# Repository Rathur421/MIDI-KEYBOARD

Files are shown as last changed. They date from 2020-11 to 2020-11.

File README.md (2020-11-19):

# 🎹 ARDUINO UNO BASED MIDI KEYBOARD WITH VELOCITY V0.1


The documentation of the code is currently being made as well as the code improved.

This project use the [Arduino MIDI Library](https://github.com/FortySevenEffects/arduino_midi_library)

:warning: the easiest way will always be to buy a midi-keyboard

Up to 88 Key(and more if needed) currently tested for 61 key without major issues.

This github repo is made to propose some (I hope) helpfull ressources to make a MIDI Keyboard wich take in charge the velocity using an arduino-uno and some multiplexer(74HC4051). This my first:

- ARDUINO based project.
- [ARDUINO library](https://github.com/Rathur421/MIDI-KEYBOARD/tree/Master/PCB/circuit) (and first C++ program).
- [PCB conception](https://github.com/Rathur421/MIDI-KEYBOARD/tree/Master/Arduino_Code/lib).

so please try to not be too rude.

The file for the arduino shield conception are [here](https://github.com/Rathur421/MIDI-KEYBOARD/tree/Master/PCB/circuit). The file were created using [Kicad](https://kicad.org/).

## How the shield works


The number of pin on an arduino is clearly not sufficient to plug directly a keyboard matrice of a large keyboard so the idea is to use some multiplexer/demultiplexer to help us.

The biggest problem of this basic idea is that the more key you had the longueur will be the execution of the loop and the less precise will be the velocity.

we use only 1 demultiplexer `READMUX` and up to 3 multiplexer `WRITE_MUX`.
They are globally define in the code ([here](https://github.com/Rathur421/MIDI-KEYBOARD/blob/Master/Arduino_Code/lib/VeloceKey/src/VeloceKey.cpp) line 4 and 6) as they are dependent of the architecture of the project.

The switch between the different multiplexer is made by activating the pin to which each of the multiplexer is link in the PCB(from pin 11 to 13 of the arduino uno board) in the [main] program (from line 23 to 30).

## How the code works

You need to initialise all the key of your actual keyboard and put it in an array as in [main][main] from line 60 and 130.

Then you update all the key and check if the state changed based on the method `YOUR_VELOCEKEY.getKeyChanged()`.
If the state changed you can do the following:

- If it is in state 2 you can send a `MIDI.sendNoteOn(YOUR_VELOCEKEY.getNote(), YOUR_VELOCEKEY.getVelocity(), 1);`.
- If it is in state 3 you can send a `MIDI.sendNoteOff(YOUR_VELOCEKEY.getNote(), YOUR_VELOCEKEY.getVelocity(), 1);`.

That is made in the function update in [main][main] from line 20 to 58.

The code use principally the library [VeloceKey](###well-how-does-the-veloceKey-library-works)

### Well how does the VeloceKey library works?

This library is made to be intuitive for the user as each physical key of the keyboard correspond to a VeloceKey object in the program.

The VeloceKey object is built around a state byte to take the less place possible of the 2kB of RAM available on the Arduino Uno.

| bit position | 7 | 6 | 5 | 4 | 3 | 2 | 1 | 0 |
| --- | --- | --- | --- | --- | --- | --- | --- | --- |
| used for | not used | not used | Key previous state 1 | Key previous state 2 | velocity state | velocity previous state | main state | main previous state |

The key of a midi keyboard is composed of two push button, the main and velocity button each one have his `actual` and `previous state` stored inside the `state byte`.

When the programme loop the `state byte` [update](####Update) and if the `previous state` doesn't match with the `actual state` then the `key state` will be changed.

#### Key state

The `key state` can be accessed via the method `YOUR_VELOCEKEY.getKeyState()` which return a byte between 0 and 3 which stand for:

- 0: Key not pressed
- 1: Key currently pressed
- 2: Key pressed
- 3: Key released

The `key state` is not directly stored inside the `byte state` as it can be deduced of the `key previous state` and the `velocity` and `main state`

#### Update

The update basically store the `key previous state` and replace the `previous state` by the `actual state` before storing the `new state` in the `actual state` if necessary.

If the `state` just passed to 1 the time is registered inside the `veloceKey` object.

If the `state` just passed to 2 the timer is used to store the velocity inside the `veloceKey` object and can be accessed with `YOUR_VELOCEKEY.getVelocity()`.

[main]: https://github.com/Rathur421/MIDI-KEYBOARD/blob/Master/Arduino_Code/src/main.cpp

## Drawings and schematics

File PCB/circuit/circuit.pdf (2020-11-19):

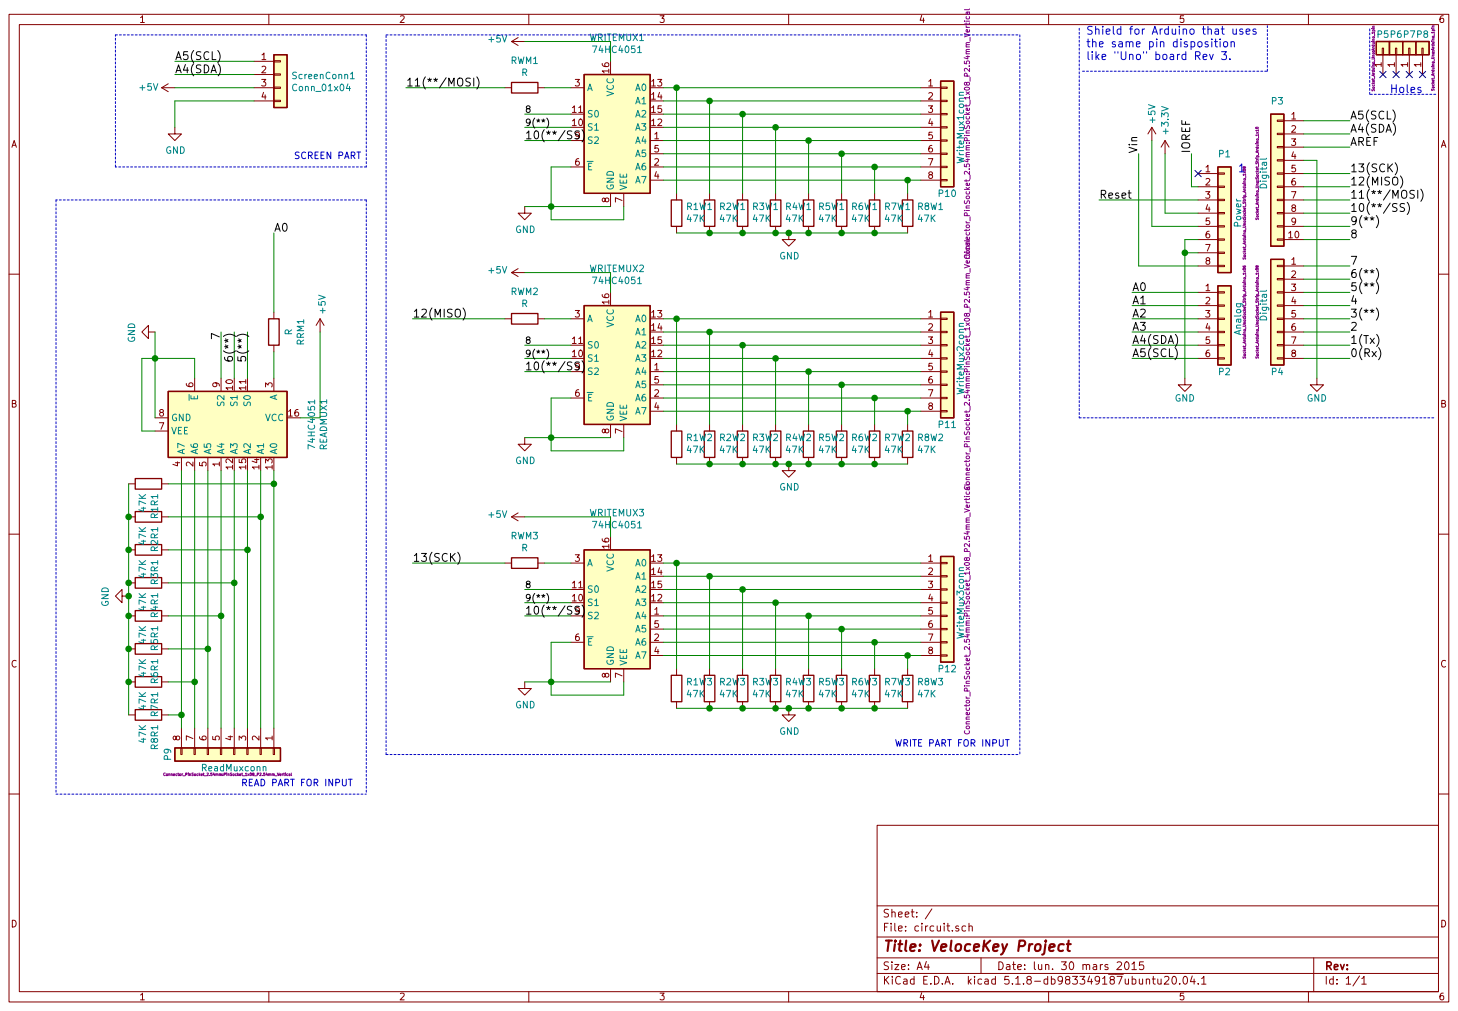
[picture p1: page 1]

the same pin disposition

Id: 1/1 Title: VeloceKey Project File: circuit.sch Sheet: /

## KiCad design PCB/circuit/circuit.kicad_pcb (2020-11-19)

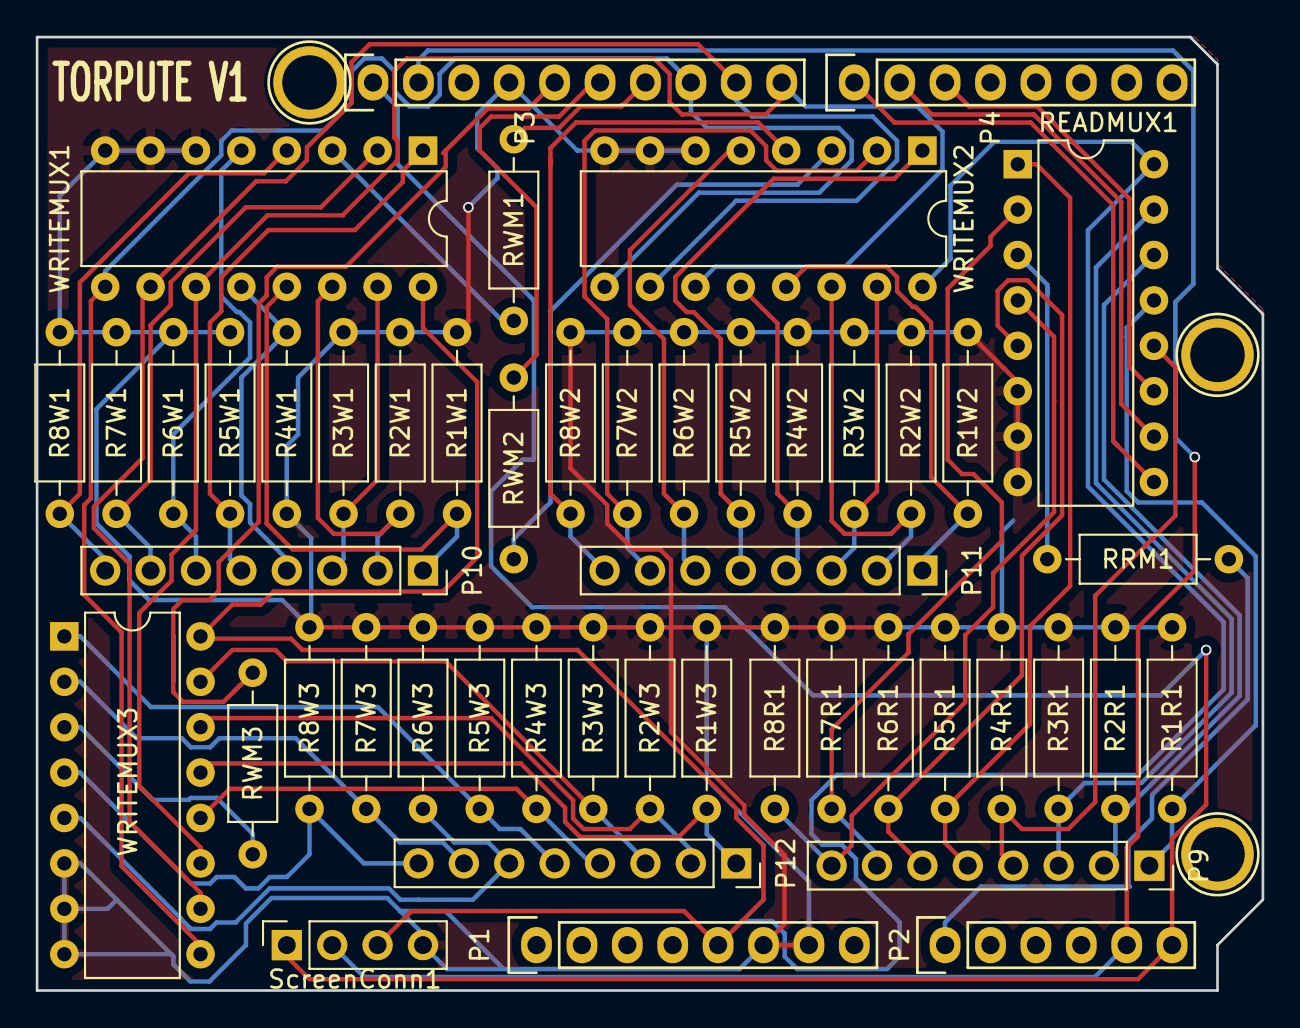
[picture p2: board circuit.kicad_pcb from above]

Board: 2 copper layers, 68.6 x 53.3 mm, 52 parts (0 on the bottom side), 50 nets.

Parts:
P1: Power; Socket_Strip_Arduino_1x08
P2: Analog; Socket_Strip_Arduino_1x06
P3: Digital; Socket_Strip_Arduino_1x10
P4: Digital; Socket_Strip_Arduino_1x08
P6, P7, P8: CONN_01X01; Arduino_1pin
P9: ReadMuxconn; PinSocket_1x08_P2.54mm_Vertical
P10: WriteMux1conn; PinSocket_1x08_P2.54mm_Vertical
P11: WriteMux2conn; PinSocket_1x08_P2.54mm_Vertical
P12: WriteMux3conn; PinSocket_1x08_P2.54mm_Vertical
R1R1, R1W1, R1W2, R1W3, R2R1, R2W1, R2W2, R2W3, R3R1, R3W1, R3W2, R3W3, R4R1, R4W1, R4W2, R4W3, R5R1, R5W1, R5W2, R5W3, R6R1, R6W1, R6W2, R6W3, R7R1, R7W1, R7W2, R7W3, R8R1, R8W1, R8W2, R8W3: 47K; R_Axial_DIN0207_L6.3mm_D2.5mm_P10.16mm_Horizontal
READMUX1: 74HC4051; DIP-16_W7.62mm
RRM1: R; R_Axial_DIN0207_L6.3mm_D2.5mm_P10.16mm_Horizontal
RWM1, RWM2, RWM3: R; R_Axial_DIN0207_L6.3mm_D2.5mm_P10.16mm_Horizontal
ScreenConn1: Conn_01x04; PinSocket_1x04_P2.54mm_Vertical
WRITEMUX1, WRITEMUX2, WRITEMUX3: 74HC4051; DIP-16_W7.62mm

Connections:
+5V: P1.5, READMUX1.16, ScreenConn1.3, WRITEMUX1.16, WRITEMUX2.16, WRITEMUX3.16
/5(**): P4.3, READMUX1.11
/6(**): P4.2, READMUX1.10
/7: P4.1, READMUX1.9
/8: P3.10, WRITEMUX1.11, WRITEMUX2.11, WRITEMUX3.11
/9(**): P3.9, WRITEMUX1.10, WRITEMUX2.10, WRITEMUX3.10
/10(**/SS): P3.8, WRITEMUX1.9, WRITEMUX2.9, WRITEMUX3.9
/11(**/MOSI): P3.7, RWM1.2
/12(MISO): P3.6, RWM2.2
/13(SCK): P3.5, RWM3.2
/A0: P2.1, RRM1.2
/A4(SDA): P2.5, P3.2, ScreenConn1.2
/A5(SCL): P2.6, P3.1, ScreenConn1.1
GND: P1.6, P1.7, P3.4, R1R1.1, R1W1.1, R1W2.1, R1W3.1, R2R1.1, R2W1.1, R2W2.1, R2W3.1, R3R1.1, R3W1.1, R3W2.1, R3W3.1, R4R1.1, R4W1.1, R4W2.1, R4W3.1, R5R1.1, R5W1.1, R5W2.1, R5W3.1, R6R1.1, R6W1.1, R6W2.1, R6W3.1, R7R1.1, R7W1.1, R7W2.1, R7W3.1, R8R1.1, R8W1.1, R8W2.1, R8W3.1, READMUX1.6, READMUX1.7, READMUX1.8, ScreenConn1.4, WRITEMUX1.6, WRITEMUX1.7, WRITEMUX1.8, WRITEMUX2.6, WRITEMUX2.7, WRITEMUX2.8, WRITEMUX3.6, WRITEMUX3.7, WRITEMUX3.8
unnamed: P9.1, R1R1.2, READMUX1.13
unnamed: P9.2, R2R1.2, READMUX1.14
unnamed: P9.3, R3R1.2, READMUX1.15
unnamed: P9.4, R4R1.2, READMUX1.12
unnamed: P9.5, R5R1.2, READMUX1.1
unnamed: P9.6, R6R1.2, READMUX1.5
unnamed: P9.7, R7R1.2, READMUX1.2
unnamed: P9.8, R8R1.2, READMUX1.4
unnamed: P10.1, R1W1.2, WRITEMUX1.13
unnamed: P10.2, R2W1.2, WRITEMUX1.14
unnamed: P10.3, R3W1.2, WRITEMUX1.15
unnamed: P10.4, R4W1.2, WRITEMUX1.12
unnamed: P10.5, R5W1.2, WRITEMUX1.1
unnamed: P10.6, R6W1.2, WRITEMUX1.5
unnamed: P10.7, R7W1.2, WRITEMUX1.2
unnamed: P10.8, R8W1.2, WRITEMUX1.4
unnamed: P11.1, R1W2.2, WRITEMUX2.13
unnamed: P11.2, R2W2.2, WRITEMUX2.14
unnamed: P11.3, R3W2.2, WRITEMUX2.15
unnamed: P11.4, R4W2.2, WRITEMUX2.12
unnamed: P11.5, R5W2.2, WRITEMUX2.1
unnamed: P11.6, R6W2.2, WRITEMUX2.5
unnamed: P11.7, R7W2.2, WRITEMUX2.2
unnamed: P11.8, R8W2.2, WRITEMUX2.4
unnamed: P12.1, R1W3.2, WRITEMUX3.13
unnamed: P12.2, R2W3.2, WRITEMUX3.14
unnamed: P12.3, R3W3.2, WRITEMUX3.15
unnamed: P12.4, R4W3.2, WRITEMUX3.12
unnamed: P12.5, R5W3.2, WRITEMUX3.1
unnamed: P12.6, R6W3.2, WRITEMUX3.5
unnamed: P12.7, R7W3.2, WRITEMUX3.2
unnamed: P12.8, R8W3.2, WRITEMUX3.4
unnamed: READMUX1.3, RRM1.1
unnamed: RWM1.1, WRITEMUX1.3
unnamed: RWM2.1, WRITEMUX2.3
unnamed: RWM3.1, WRITEMUX3.3

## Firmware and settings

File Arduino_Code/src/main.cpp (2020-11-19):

#include <Arduino.h>

#include <rgb_lcd.h>

#include <VeloceKey.h>

#include <MIDI.h>


MIDI_CREATE_DEFAULT_INSTANCE();


// Init SCREEN
rgb_lcd lcd;

byte nb_note_on = 0;

// DEBOUNCE = 5
// Function
void update(VeloceKey KEYS[], int key_number){

  for (int i=0; i<key_number; i++){
    if (i==0){
      digitalWrite(12, LOW);
      digitalWrite(11, HIGH);
    }
    if (i==32){
      digitalWrite(12, HIGH);
      digitalWrite(11, LOW);
    }

    KEYS[i].update();
    if (KEYS[i].getKeyChanged()){

      if (KEYS[i].getKeyState()==2){
        MIDI.sendNoteOn(KEYS[i].getNote(), KEYS[i].getVelocity(), 1);
        lcd.clear();
        lcd.write("NOTE:");
        lcd.print(KEYS[i].getNote());
        lcd.setCursor(0,2);
        lcd.write("Velocity:");
        lcd.print(KEYS[i].getVelocity());
        nb_note_on++;
        if (nb_note_on>0){
          lcd.setRGB(127,200,127);
        }

      }
      else if (KEYS[i].getKeyState()==3){
        MIDI.sendNoteOff(KEYS[i].getNote(), KEYS[i].getVelocity(), 1);
        nb_note_on--;
        if (nb_note_on==0){
          lcd.setRGB(127,127,127);
        }
      }
    }
  }
}

// Init Keynote
// Keynote K0 = Keynote(write_mux_adresse, read_mux_adresse, Note);
VeloceKey NC2  = VeloceKey(0, 0, 24);
VeloceKey NCd2 = VeloceKey(0, 1, 25);
VeloceKey ND2  = VeloceKey(0, 2, 26);
VeloceKey NDd2 = VeloceKey(0, 3, 27);
VeloceKey NE2  = VeloceKey(0, 4, 28);
VeloceKey NF2  = VeloceKey(0, 5, 29);
VeloceKey NFd2 = VeloceKey(0, 6, 30);
VeloceKey NG2  = VeloceKey(0, 7, 31);
VeloceKey NGd2 = VeloceKey(2, 0, 32);
VeloceKey NA3  = VeloceKey(2, 1, 33);
VeloceKey NAd3 = VeloceKey(2, 2, 34);
VeloceKey NB3  = VeloceKey(2, 3, 35);
VeloceKey NC3  = VeloceKey(2, 4, 36);
VeloceKey NCd3 = VeloceKey(2, 5, 37);
VeloceKey ND3  = VeloceKey(2, 6, 38);
VeloceKey NDd3 = VeloceKey(2, 7, 39);
VeloceKey NE3  = VeloceKey(4, 0, 40);
VeloceKey NF3  = VeloceKey(4, 1, 41);
VeloceKey NFd3 = VeloceKey(4, 2, 42);
VeloceKey NG3  = VeloceKey(4, 3, 43);
VeloceKey NGd3 = VeloceKey(4, 4, 44);
VeloceKey NA4  = VeloceKey(4, 5, 45);
VeloceKey NAd4 = VeloceKey(4, 6, 46);
VeloceKey NB4  = VeloceKey(4, 7, 47);
VeloceKey NC4  = VeloceKey(6, 0, 48);
VeloceKey NCd4 = VeloceKey(6, 1, 49);
VeloceKey ND4  = VeloceKey(6, 2, 50);
VeloceKey NDd4 = VeloceKey(6, 3, 51);
VeloceKey NE4  = VeloceKey(6, 4, 52);
VeloceKey NF4  = VeloceKey(6, 5, 53);
VeloceKey NFd4 = VeloceKey(6, 6, 54);
VeloceKey NG4  = VeloceKey(6, 7, 55);
VeloceKey NGd4 = VeloceKey(0, 0, 56);
VeloceKey NA5  = VeloceKey(0, 1, 57);
VeloceKey NAd5 = VeloceKey(0, 2, 58);
VeloceKey NB5  = VeloceKey(0, 3, 59);
VeloceKey NC5  = VeloceKey(0, 4, 60);
VeloceKey NCd5 = VeloceKey(0, 5, 61);
VeloceKey ND5  = VeloceKey(0, 6, 62);
VeloceKey NDd5 = VeloceKey(0, 7, 63);
VeloceKey NE5  = VeloceKey(2, 0, 64);
VeloceKey NF5  = VeloceKey(2, 1, 65);
VeloceKey NFd5 = VeloceKey(2, 2, 66);
VeloceKey NG5  = VeloceKey(2, 3, 67);
VeloceKey NGd5 = VeloceKey(2, 4, 68);
VeloceKey NA6  = VeloceKey(2, 5, 69);
VeloceKey NAd6 = VeloceKey(2, 6, 70);
VeloceKey NB6  = VeloceKey(2, 7, 71);
VeloceKey NC6  = VeloceKey(4, 0, 72);
VeloceKey NCd6 = VeloceKey(4, 1, 73);
VeloceKey ND6  = VeloceKey(4, 2, 74);
VeloceKey NDd6 = VeloceKey(4, 3, 75);
VeloceKey NE6  = VeloceKey(4, 4, 76);
VeloceKey NF6  = VeloceKey(4, 5, 77);
VeloceKey NFd6 = VeloceKey(4, 6, 78);
VeloceKey NG6  = VeloceKey(4, 7, 79);
VeloceKey NGd6 = VeloceKey(6, 0, 80);
VeloceKey NA7  = VeloceKey(6, 1, 81);
VeloceKey NAd7 = VeloceKey(6, 2, 82);
VeloceKey NB7  = VeloceKey(6, 3, 83);
VeloceKey NC7  = VeloceKey(6, 4, 84);


const byte nb_key = 61;
VeloceKey Keypad[nb_key] = {NC2, NCd2, ND2, NDd2, NE2, NF2, NFd2, NG2, NGd2, NA3, NAd3, NB3,
  NC3, NCd3, ND3, NDd3, NE3, NF3, NFd3, NG3, NGd3, NA4, NAd4, NB4,
  NC4, NCd4, ND4, NDd4, NE4, NF4, NFd4, NG4, NGd4, NA5, NAd5, NB5,
  NC5, NCd5, ND5, NDd5, NE5, NF5, NFd5, NG5, NGd5, NA6, NAd6, NB6,
  NC6, NCd6, ND6, NDd6, NE6, NF6, NFd6, NG6, NGd6, NA7, NAd7, NB7, NC7};
// const byte nb_key = 1;
// VeloceKey Keypad[nb_key] = {NE3};

static Mux74HC4051 WRITE_MUX(1, 8, 9, 10, 1);
void setup() {
  MIDI.begin();
  lcd.begin(16, 2);
  Serial.begin(115200);
  pinMode(11,OUTPUT);
  pinMode(12,OUTPUT);
  pinMode(13,OUTPUT);
  lcd.setRGB(127,127,127);
  // Serial.println("helloworld");
}

void loop() {
  update(Keypad, nb_key);
  // WRITE_MUX.setChannel(4);
  // digitalWrite(11,HIGH);
  // digitalWrite(12,HIGH);
  // NC2.MainSwitchupdate();
  // Serial.println(analogRead(14));
}
